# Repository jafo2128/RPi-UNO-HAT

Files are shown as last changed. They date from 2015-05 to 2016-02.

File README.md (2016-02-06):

# RPi-UNO-HAT
Raspberry Pi to Arduino/Genuino Shield Bridge.

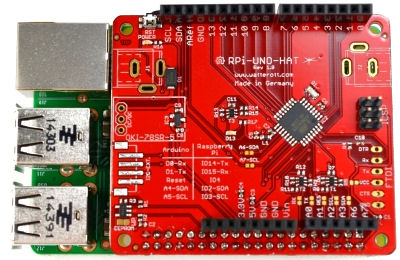
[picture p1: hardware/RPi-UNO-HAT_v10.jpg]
RPi-UNO-HAT (http://www.watterott.com/en/RPi-UNO-HAT)


## Shop
* [RPi-UNO-HAT](http://www.watterott.com/en/RPi-UNO-HAT)

## Features
* Atmel AVR ATmega328 with Arduino compatible Bootloader (optiboot)
* Raspberry Pi connected via I2C and UART (to the AVR through level-shifter)
* AVR-Programming via Raspberry Pi possible
* Shield connectors with Uno R3 layout
* Additional 3.3V LDO voltage regulator for Shields
* Optional 7-36V power input for Raspberry Pi and RPi-UNO-HAT (Murata OKI-78SR-5)

## Hardware and Software
* [Schematics + Layout](https://github.com/watterott/RPi-UNO-HAT/tree/master/hardware)
* [How to install the Arduino IDE on Raspberry Pi](https://github.com/watterott/RPi-UNO-HAT/blob/master/docu/Arduino.md)
* [How to control the RPi-UNO-HAT with Firmata](https://github.com/watterott/RPi-UNO-HAT/blob/master/docu/Firmata.md)
* [How to communicate with the RPi-UNO-HAT via I2C](https://github.com/watterott/RPi-UNO-HAT/blob/master/docu/I2CTest.md)
* [How to flash/update EEPROM on the RPi-UNO-HAT](https://github.com/watterott/RPi-UNO-HAT/blob/master/docu/EEPROM.md)
* [Nuage a Arduino Yún compatible device](http://www.arduino-hausautomation.de/nuage/)

Finally words from us Archivers and Developers.. 

##### Donate

People from time to time wish to donate a little money. Donating won't get you anything special, other than a warm feeling inside, and possibly urge me to produce more freely available material for interesting projects. You can donate via [PayPal](https://www.paypal.com), just click [donate](https://www.paypal.com/cgi-bin/webscr?cmd=_s-xclick&hosted_button_id=3PXVSLXFBS45E) button available below - it will redirect you to the secured PayPal page where you can provide donation amount (there is no minimal value). Any donations are apreciated greatly, and we thank you all in advance for your support along the ways..



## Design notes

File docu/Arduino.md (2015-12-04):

# Arduino IDE on Raspberry Pi with RPi-UNO-HAT

For using the Arduino IDE to program the AVR microcontroller on the RPi-UNO-HAT the jumpers **TX**, **RX** and **RES** have to be closed, which is also the default state of these jumpers.

* Install the Arduino IDE:

    ```
    $ sudo apt-get update
    $ sudo apt-get install arduino
    ```

* Install [Auto-Reset for AVRdude](https://github.com/CisecoPlc/avrdude-rpi) on GPIO4 (Pin 7):

    ```
    $ wget https://github.com/watterott/RPi-UNO-HAT/raw/master/docu/autoreset
    $ wget https://github.com/watterott/RPi-UNO-HAT/raw/master/docu/avrdude-autoreset
    $ chmod +x autoreset
    $ chmod +x avrdude-autoreset
    $ sudo mv autoreset /usr/bin
    $ sudo mv avrdude-autoreset /usr/bin
    $ sudo mv /usr/bin/avrdude /usr/bin/avrdude-original
    $ sudo ln -s /usr/bin/avrdude-autoreset /usr/bin/avrdude
    ```

* [Disable Linux serial console](http://elinux.org/RPi_Serial_Connection#Preventing_Linux_using_the_serial_port):

    ```
    $ sudo raspi-config
    ```

    Select:
    ```
    Advanced > Disable shell and kernel messages on the serial connection.
    ```

    Reboot the system:
    ```
    $ sudo reboot
    ```

  * If there are any problems the changes can also be made with nano:
        ```
        $ sudo nano /boot/cmdline.txt
        ```
        Remove references to ```console=ttyAMA0,115200``` and ```kgdboc=ttyAMA0,115200```.

        ```
        $ sudo nano /etc/inittab
        ```
        Remove or comment the line ```T0:23:respawn:/sbin/getty -L ttyAMA0 115200 vt100```.

* Test AVRdude:

    ```
    $ sudo avrdude -c arduino -p m328p -P /dev/ttyAMA0 -b 57600 -v
    ```

    The device signature of the ATmega328 is *0x1e950f*.

* Run the Arduino IDE.

* Select **Arduino Uno** under **Tools->Board**.

* Select the hardware serial port **/dev/ttyAMA0** under **Tools->Serial Port**.

    If the hardware serial port is not recognized then create a symlink to the standard Linux serial port *ttyS0*:

    ```
    $ sudo nano /etc/udev/rules.d/80-arduinopi.rules

    KERNEL=="ttyAMA0", SYMLINK+="ttyS0",GROUP="dialout",MODE:=0666
    ```

    Another problem can be if the user, that runs the Arduino IDE, is not a member of the dialout group ([further infos](http://elinux.org/RPi_Serial_Connection)).
    To add a user to the group run:

    ```
    $ sudo usermod -a -G dialout USERNAME
    ```

* Open the Blink Sketch under **File->Examples->01.Basics->Blink**.

* Start build and upload: **File->Upload**.

* The LED D13 on the RPi-UNO-HAT will start to blink after the upload is finished.

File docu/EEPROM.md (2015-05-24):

# How to flash/update the ID EEPROM?

The EEPROM on the HAT can be updated as follows.
Before the update the **WP** jumper next to the EEPROM has to be closed.

* Install [EEPROM utils](https://github.com/raspberrypi/hats/tree/master/eepromutils):
    ```
    $ git clone --depth=1 https://github.com/raspberrypi/hats
    $ cd hats/eepromutils
    $ make
    $ chmod +x eepflash.sh
    ```

* Generate EEPROM data:
    ```
    $ wget https://github.com/watterott/RPi-UNO-HAT/raw/master/docu/rpi-uno-hat.txt
    $ ./eepmake rpi-uno-hat.txt rpi-uno-hat.eep
    ```

* Update/Flash EEPROM:
    ```
    $ sudo ./eepflash.sh -w -t=24c32 -f=rpi-uno-hat.eep
    ```
    Note: For a Device Tree Kernel add to ```/boot/config.txt``` the following line before flashing: ```dtparam=i2c0=on``` (before any dtoverlay statement).

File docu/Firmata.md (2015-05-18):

# Firmata

[Firmata](http://firmata.org) is a protocol for communicating with microcontrollers from software on a host computer.
So you can control an Arduino with a Raspberry Pi using Firmata.

There is a tutorial for Firmata and Raspberry Pi in [The MagPi Issue 7](http://www.themagpi.com/en/issue/7) and here is also a small guide.

## Prepare RPi-UNO-HAT

* **Sketch upload via hardware serial port of the Raspberry Pi**
  * The jumpers **TX**, **RX** and **RES** have to be closed, which is also the default state of these jumpers.
  * [Install the Arduino IDE on the Raspberry Pi](https://github.com/watterott/RPi-UNO-HAT/blob/master/docu/Arduino.md).
  * Start the Arduino IDE.
  * Select **Arduino Uno** under **Tools->Board**.
  * Choose the hardware serial port **/dev/ttyAMA0** under **Tools->Serial Port**.
  * Open the Firmata Sketch under **File->Examples->Firmata->StandardFirmata**.
  * Start build and upload: **File->Upload**.
  * Now exit the Arduino IDE.

* **Sketch upload with USB FTDI adapter**
  * Download and install the [Arduino IDE](http://arduino.cc/en/Main/Software) on your computer or [Raspberry Pi](https://github.com/watterott/RPi-UNO-HAT/blob/master/docu/Arduino.md).
  * Close the **VCC Jumper** next to the FTDI connector to power the RPi-UNO-HAT from the FTDI adapter or put it on a Raspberry Pi for powering. 
  * Connect the RPi-UNO-HAT with a FTDI adapter (5V) to the computer or Raspberry Pi.
  * Start the Arduino IDE.
  * Select **Arduino Uno** under **Tools->Board**.
  * Choose the serial port from the FTDI adapter under **Tools->Serial Port**.
  * Open the Firmata Sketch under **File->Examples->Firmata->StandardFirmata**.
  * Start build and upload: **File->Upload**.
  * Now exit the Arduino IDE.

## Prepare Raspberry Pi

The RPi-UNO-HAT can be connected via USB or UART:

* **USB connection (FTDI adapter)**
  * Put the RPi-UNO-HAT on the Raspberry Pi.
  * Connect a FTDI adapter (5V) to the USB port of the Raspberry Pi and FTDI connector on the RPi-UNO-HAT.
  * Device name: */dev/ttyUSB0* or */dev/ttyACM0*

* **UART connection (hardware serial port)**
  * Put the RPi-UNO-HAT on the Raspberry Pi.
  * [Disable Linux serial console](http://elinux.org/RPi_Serial_Connection#Preventing_Linux_using_the_serial_port).
  * Device name: */dev/ttyAMA0*

## Controlling with Python

* Install [pySerial](http://pyserial.sourceforge.net) and [pyFirmata](https://github.com/tino/pyFirmata) using [pip](http://www.pip-installer.org/en/latest/installing.html):

    ```
    $ sudo apt-get update
    $ sudo apt-get install python-serial
    $ sudo pip install pyfirmata
    ```

* Create a test script named [Firmata.py](https://github.com/watterott/RPi-UNO-HAT/raw/master/docu/Firmata.py):

    ```
    $ nano Firmata.py

    import time
    import pyfirmata
    
    # start connection to Arduino
    #  USB: /dev/ttyUSB0 or /dev/ttyACM0
    #  UART: /dev/ttyAMA0
    board = pyfirmata.Arduino('/dev/ttyAMA0')
    
    board.digital[13].write(1) # switch on LED
    time.sleep(3)              # 3s delay
    board.digital[13].write(0) # switch off LED
    time.sleep(3)              # 3s delay
    board.exit()
    ```

* Run the script:

    ```
    $ python Firmata.py
    ```

## Controlling with Node.js (JavaScript)

* Install [Node](http://elinux.org/Node.js_on_RPi) and [Firmata library](https://npmjs.org/package/firmata):

    ```
    $ sudo apt-get install node
    $ sudo npm install -g firmata
    ```
    If the *node* package is not found then add Adafruit to the package repository:
    ```curl -sLS https://apt.adafruit.com/add | sudo bash```

* Create a test script named [Firmata.js](https://github.com/watterott/RPi-UNO-HAT/raw/master/docu/Firmata.js):

    ```
    $ nano Firmata.js

    var firmata = require('firmata');
    
    // start connection to Arduino
    //  USB: /dev/ttyUSB0 or /dev/ttyACM0
    //  UART: /dev/ttyAMA0
    var board = new firmata.Board('/dev/ttyAMA0', function(err)
    {
      if(err)
      {
        console.log(err);
        return;
      }
      console.log('connected');
      board.pinMode(13, board.MODES.OUTPUT);
      // switch on LED
      board.digitalWrite(13, board.HIGH);
      // switch off LED after 3s
      setTimeout(function()
      {
        board.digitalWrite(13, board.LOW);
        process.exit(0);
      }, 3000);
    });
    ```

* Run the script:

    ```
    $ sudo node Firmata.js
    ```

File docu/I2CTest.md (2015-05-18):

# I2C Test

A small guide to show the communication via I2C between the Arduino (RPi-UNO-HAT) and Raspberry Pi.

The I2C pins of the Raspberry Pi are connected to the AVR and the Shield connectors (SDA+SCL) on the RPi-UNO-HAT. 

## Prepare RPi-UNO-HAT

Upload the following [Sketch](https://github.com/watterott/RPi-UNO-HAT/raw/master/docu/I2CTest.ino):
```
#include <Wire.h> 

#define ADDRESS 0x30

void setup() 
{
  pinMode(13, OUTPUT);     // set pin 13 as output (LED connected)
  digitalWrite(13, LOW);   // set pin 13 to low (0V)

  Wire.begin(ADDRESS);     // join I2C bus with respective address
  Wire.onReceive(receive); // receive data function
  Wire.onRequest(request); // send data function
} 

void loop() 
{
  // do nothing
} 

void receive(int numBytes) // function that runs when data is received
{
  unsigned char c;

  while(Wire.available())
  { 
    c = Wire.read();
    if(c == 0x00)      // LED off, if byte equals 0
    {
      digitalWrite(13, LOW);
    }
    else if(c == 0x01) // LED on, if byte equals 1
    {
      digitalWrite(13, HIGH);
    }
  }
}

void request() // function that runs when data is requested
{
  Wire.write(0xAA); // send 0xAA
}
```

## Prepare Raspberry Pi

* Activate I2C:

    ```
    $ sudo modprobe i2c_bcm2708 baudrate=100000
    $ sudo modprobe i2c-dev
    ```
    Note: For a Device Tree Kernel add to ```/boot/config.txt``` the following line: ```dtparam=i2c1=on``` (before any dtoverlay statement).

* Install i2c-tools and python-smbus:

    ```
    $ sudo apt-get install i2c-tools
    $ sudo apt-get install python-smbus
    ```

* Test I2C bus:

    ```
    $ sudo i2cdetect -y 1
    ```

### Shell

* Switch on LED:

    ```
    $ sudo i2cset -y 1 0x30 0x01
    ```

* Switch off LED:

    ```
    $ sudo i2cset -y 1 0x30 0x00
    ```

### Python

* Create a test script named [I2CTest.py](https://github.com/watterott/RPi-UNO-HAT/raw/master/docu/I2CTest.py):

    ```
    $ nano I2CTest.py

    import time
    import smbus
    bus = smbus.SMBus(1)
    addr = 0x30
    
    while True:
        bus.write_byte(addr, 0x01)
        print "on"
        time.sleep(1)
        bus.write_byte(addr, 0x00)
        print "off"
        time.sleep(1)
    ```

* Run the script:

    ```
    $ sudo python I2CTest.py
    ```

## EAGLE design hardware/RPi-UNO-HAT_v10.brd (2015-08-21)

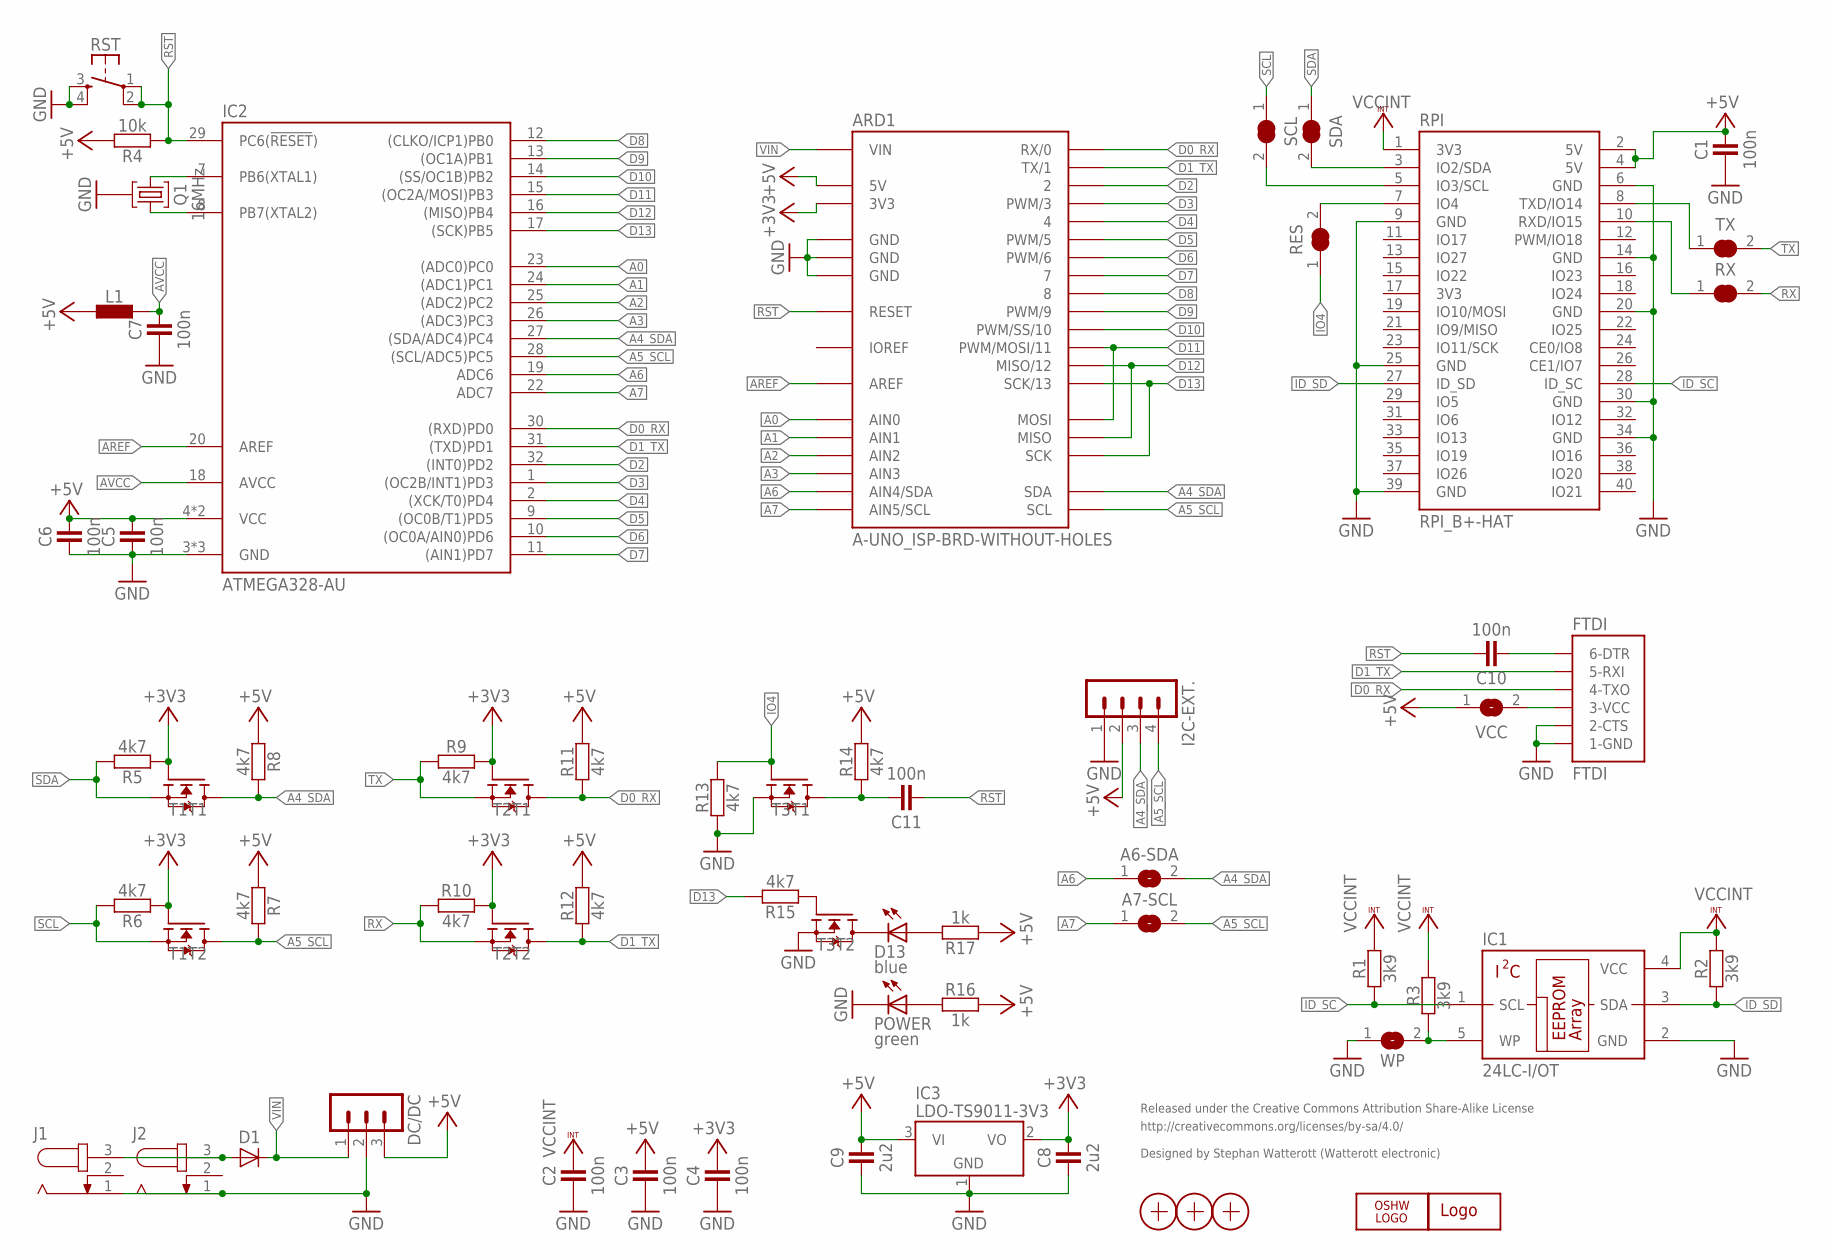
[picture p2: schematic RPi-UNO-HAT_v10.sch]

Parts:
A6-SDA, A7-SCL: JUMPER2-0402-NC; JUMPER2-0402_NC
ARD1: A-UNO_ISP-BRD-WITHOUT-HOLES; A-UNO-ISP_CON-WITHOUT-HOLES
C1, C2, C3, C4, C5, C6, C7, C10, C11: 100n; C0402
C8, C9: 2u2; C0402
D1: DIODE-SOD80; SOD80
D13: blue; C0603
DC/DC: MA03-1
FTDI: FTDI
I2C-EXT.: JST_PH_4B4B-PH-SM4-TB; JST_B4B-PH-SM4-TB
IC1: 24LC-I/OT; SOT23-5
IC2: ATMEGA328-AU; TQFP32
IC3: LDO-TS9011-3V3; SOT23
J1, J2: DC-JACK
L1: INDUCTOR-0603; C0603
LOGO1: LOGO-S_PLACE_S; SPARK_TPLACE_S
LOGO2: OSHW_LOGOX0070; OSHW_6X70
POWER: green; C0603
Q1: 16MHz; CRYSTAL_32X13
R1, R2, R3: 3k9; C0402
R4: 10k; C0402
R5, R6, R7, R8, R9, R10, R11, R12, R13, R14, R15: 4k7; C0402
R16, R17: 1k; C0402
RES: JUMPER2-0402-NC; JUMPER2-0402_NC
RPI: RPI_B+-HAT; RPI-B+HAT
RST: SW-TACTILE-PTS840P; SW_PTS840P
RX: JUMPER2-0402-NC; JUMPER2-0402_NC
SCL: JUMPER2-0402-NC; JUMPER2-0402_NC
SDA: JUMPER2-0402-NC; JUMPER2-0402_NC
T1, T2, T3: BSS138PS; SOT363
TX: JUMPER2-0402-NC; JUMPER2-0402_NC
VCC: JUMPER2-0402-NC; JUMPER2-0402_NC
WP: JUMPER2-0603-NC; JUMPER2-0603_NC
X1, X2, X3: PASSER-07; PASSER_07MM

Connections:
+3V3: ARD1.3V3, C4.2, C8.2, IC3.2 (VO), R5.1, R6.1, R9.2, R10.2, T1.2 (G), T1.5 (G), T2.2 (G), T2.5 (G)
+5V: ARD1.5V, ARD1.VCC (5V), C1.2, C3.2, C5.2, C6.2, C9.2, DC/DC.3, I2C-EXT..2, IC2.4 (VCC), IC2.6 (VCC), IC3.3 (VI), L1.1, R4.2, R7.1, R8.1, R11.2, R12.2, R14.2, R16.2, R17.1, RPI.2 (5V), RPI.4 (5V), VCC.1
A0: ARD1.A0 (AIN0), IC2.23 ((ADC0)PC0)
A1: ARD1.A1 (AIN1), IC2.24 ((ADC1)PC1)
A2: ARD1.A2 (AIN2), IC2.25 ((ADC2)PC2)
A3: ARD1.A3 (AIN3), IC2.26 ((ADC3)PC3)
A4_SDA: A6-SDA.2, ARD1.SDA, I2C-EXT..3, IC2.27 ((SDA/ADC4)PC4), R8.2, T1.6 (D)
A5_SCL: A7-SCL.2, ARD1.SCL, I2C-EXT..4, IC2.28 ((SCL/ADC5)PC5), R7.2, T1.3 (D)
A6: A6-SDA.1, ARD1.A4 (AIN4/SDA), IC2.19 (ADC6)
A7: A7-SCL.1, ARD1.A5 (AIN5/SCL), IC2.22 (ADC7)
AREF: ARD1.AREF, IC2.20 (AREF)
AVCC: C7.2, IC2.18 (AVCC), L1.2
D0_RX: ARD1.0 (RX/0), FTDI.4-TX (4-TXO), IC2.30 ((RXD)PD0), R11.1, T2.6 (D)
D0_RX1: C11.2, R14.1, T3.6 (D)
D1_TX: ARD1.1 (TX/1), FTDI.5-RX (5-RXI), IC2.31 ((TXD)PD1), R12.1, T2.3 (D)
D2: ARD1.2, IC2.32 ((INT0)PD2)
D3: ARD1.3 (PWM/3), IC2.1 ((OC2B/INT1)PD3)
D4: ARD1.4, IC2.2 ((XCK/T0)PD4)
D5: ARD1.5 (PWM/5), IC2.9 ((OC0B/T1)PD5)
D6: ARD1.6 (PWM/6), IC2.10 ((OC0A/AIN0)PD6)
D7: ARD1.7, IC2.11 ((AIN1)PD7)
D8: ARD1.8, IC2.12 ((CLKO/ICP1)PB0)
D9: ARD1.9 (PWM/9), IC2.13 ((OC1A)PB1)
D10: ARD1.10 (PWM/SS/10), IC2.14 ((SS/OC1B)PB2)
D11: ARD1.11 (PWM/MOSI/11), ARD1.MOSI, IC2.15 ((OC2A/MOSI)PB3)
D12: ARD1.12 (MISO/12), ARD1.MISO, IC2.16 ((MISO)PB4)
D13: ARD1.13 (SCK/13), ARD1.SCK, IC2.17 ((SCK)PB5), R15.2
GND: ARD1.GND@1 (GND), ARD1.GND@2 (GND), ARD1.GND@3 (GND), ARD1.GND@4 (GND), C1.1, C2.1, C3.1, C4.1, C5.1, C6.1, C7.1, C8.1, C9.1, DC/DC.2, FTDI.1-GND, FTDI.2-CTS, I2C-EXT..1, IC1.2 (GND), IC2.3 (GND), IC2.5 (GND), IC2.21 (GND), IC3.1 (GND), J1.1, J2.1, POWER.C, Q1.GND, R13.1, RPI.6 (GND), RPI.9 (GND), RPI.14 (GND), RPI.20 (GND), RPI.25 (GND), RPI.30 (GND), RPI.34 (GND), RPI.39 (GND), RST.3 (S1), RST.4 (S2), T3.1 (S), T3.4 (S), WP.1
ID_SC: IC1.1 (SCL), R1.1, RPI.28 (ID_SC)
ID_SD: IC1.3 (SDA), R2.1, RPI.27 (ID_SD)
IO4: R13.2, RES.1, T3.2 (G)
IOREF: ARD1.IOREF
unnamed: IC2.8 (PB7(XTAL2)), Q1.1
unnamed: IC2.7 (PB6(XTAL1)), Q1.2
unnamed: D1.A, J1.3, J2.3
unnamed: C10.1, FTDI.6-DTR
unnamed: RPI.8 (TXD/IO14), TX.1
unnamed: RPI.10 (RXD/IO15), RX.1
unnamed: RES.2, RPI.7 (IO4)
unnamed: FTDI.3-VCC, VCC.2
unnamed: RPI.5 (IO3/SCL), SCL.2
unnamed: RPI.3 (IO2/SDA), SDA.2
unnamed: R15.1, T3.5 (G)
unnamed: POWER.A, R16.1
unnamed: D13.A, R17.2
unnamed: D13.C, T3.3 (D)
RST: ARD1.RST (RESET), ARD1.RST2 (RESET), C10.2, C11.1, IC2.29 (PC6(!RESET!)), R4.1, RST.1, RST.2
RX: R10.1, RX.2, T2.4 (S)
SCL: R6.2, SCL.1, T1.4 (S)
SDA: R5.2, SDA.1, T1.1 (S)
TX: R9.1, T2.1 (S), TX.2
VCCINT: C2.2, IC1.4 (VCC), R1.2, R2.2, R3.2, RPI.1 (3V3)
VIN: ARD1.VIN, D1.C, DC/DC.1
WP: IC1.5 (WP), R3.1, WP.2

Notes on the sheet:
Released under the Creative Commons Attribution Share-Alike License
http://creativecommons.org/licenses/by-sa/4.0/
Designed by Stephan Watterott (Watterott electronic)

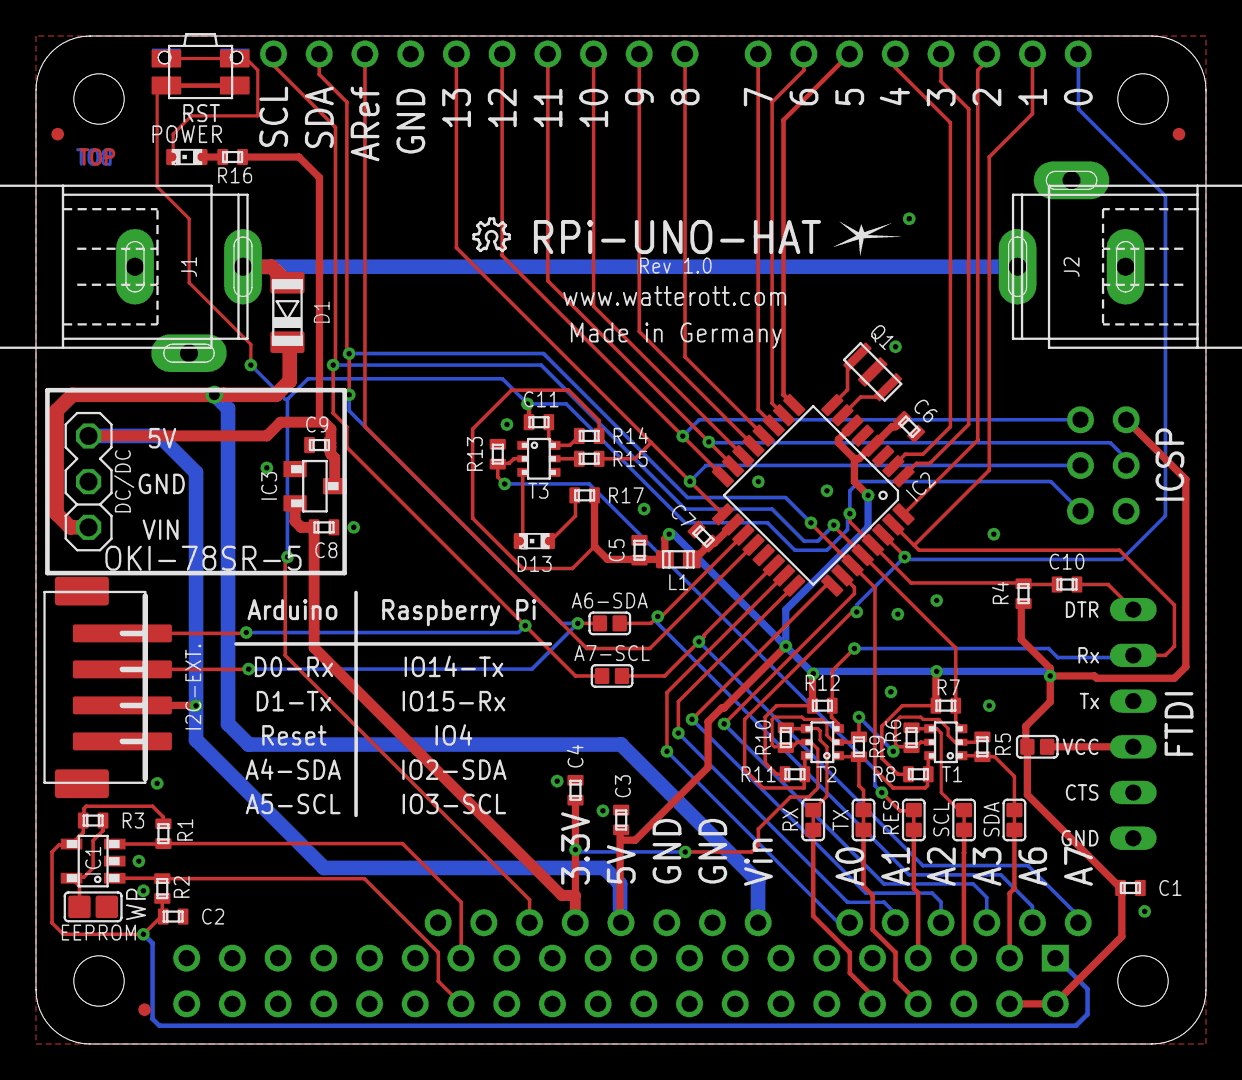
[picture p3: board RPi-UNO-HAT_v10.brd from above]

Board: 2 copper layers, 65.0 x 56.0 mm, 61 parts (0 on the bottom side), 53 nets.

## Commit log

2015-05-09 added schematics and layout
    [RPi-UNO-HAT_v10.brd, RPi-UNO-HAT_v10.sch]
2015-08-21 changed path structure
    [RPi-UNO-HAT_v10.brd, RPi-UNO-HAT_v10.sch]
